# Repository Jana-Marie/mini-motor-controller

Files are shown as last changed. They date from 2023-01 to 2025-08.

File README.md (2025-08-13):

# mini-motor-controller

A motor controller for miniature stepper motors, such as used in CD head drives. The additional ADC input allows for position feedback. This project was intended to be used in a DIY motor fader, however this motorfader has not been designed yet.

It features a cheap STM32F030 as brains with I2C as main IO to the host controller, an onboard regulator allows for an input voltage of up to 10V. The motor driver is a STSPIN220 with up to 1.3Arms.

<table>
  <tbody>
    <tr>
      <td colspan="2">
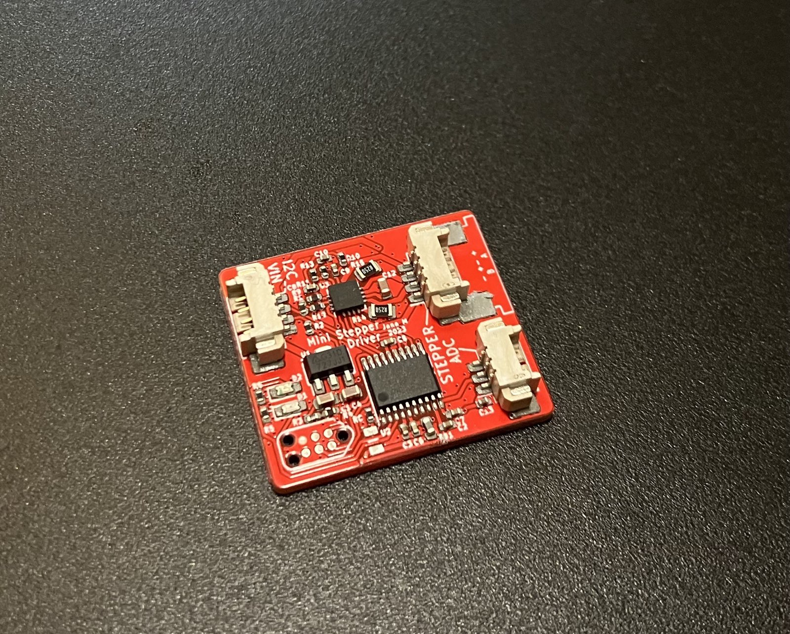
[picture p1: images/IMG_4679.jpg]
        
      </td>
    </tr>
    <tr>
      <td>
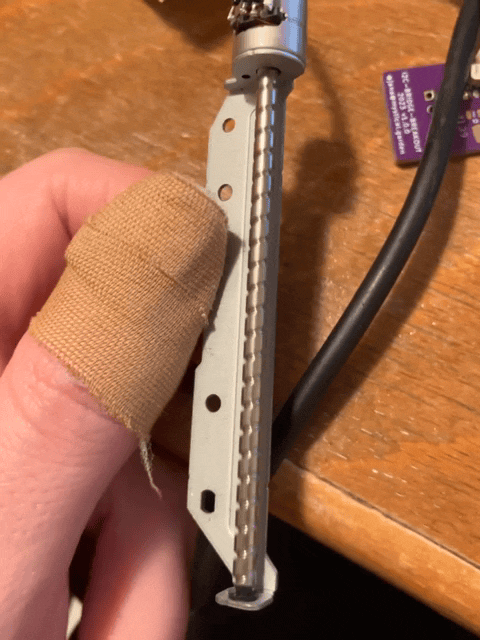
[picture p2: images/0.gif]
        
      </td>
      <td>
        
      </td>
    </tr>
    <tr>
      <td>
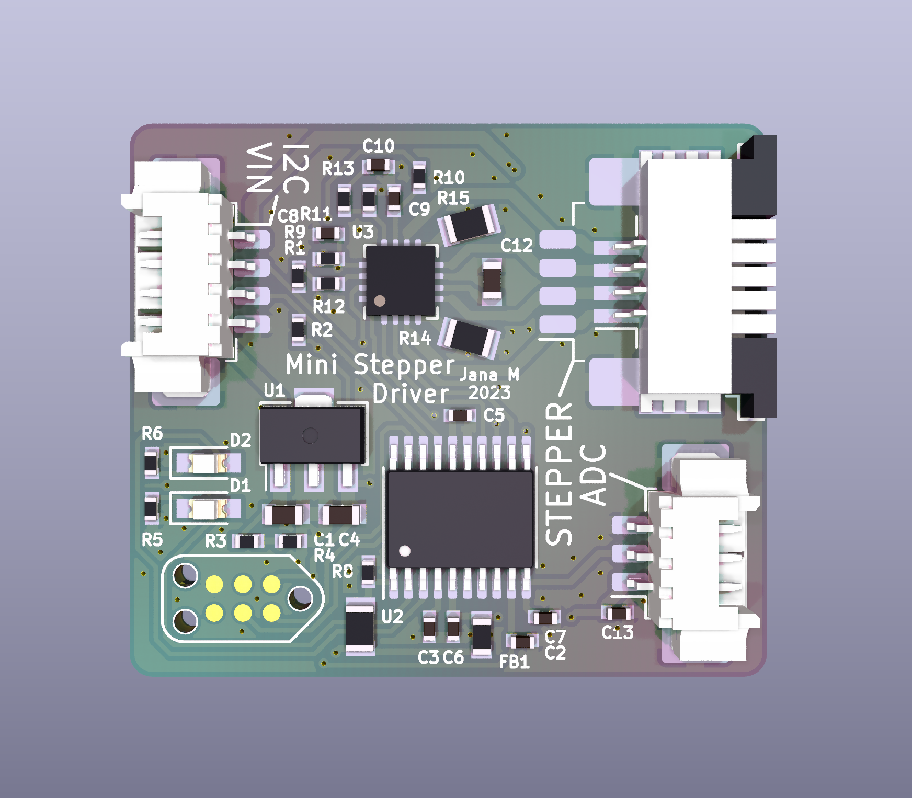
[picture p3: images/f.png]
        
      </td>
      <td>
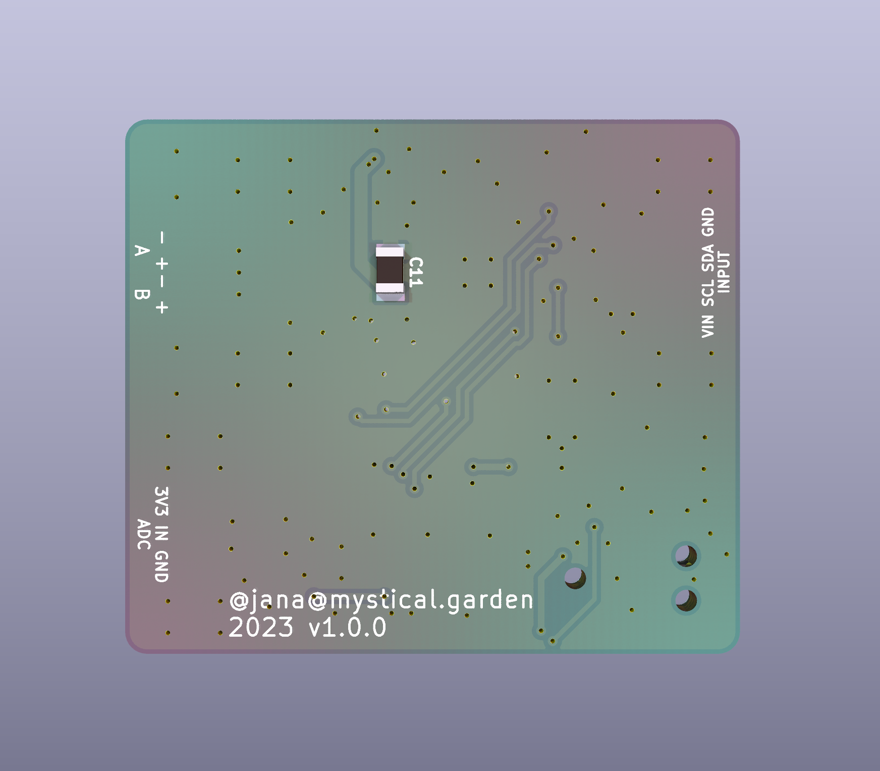
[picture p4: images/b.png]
        
      </td>
    </tr>
  </tbody>
</table>

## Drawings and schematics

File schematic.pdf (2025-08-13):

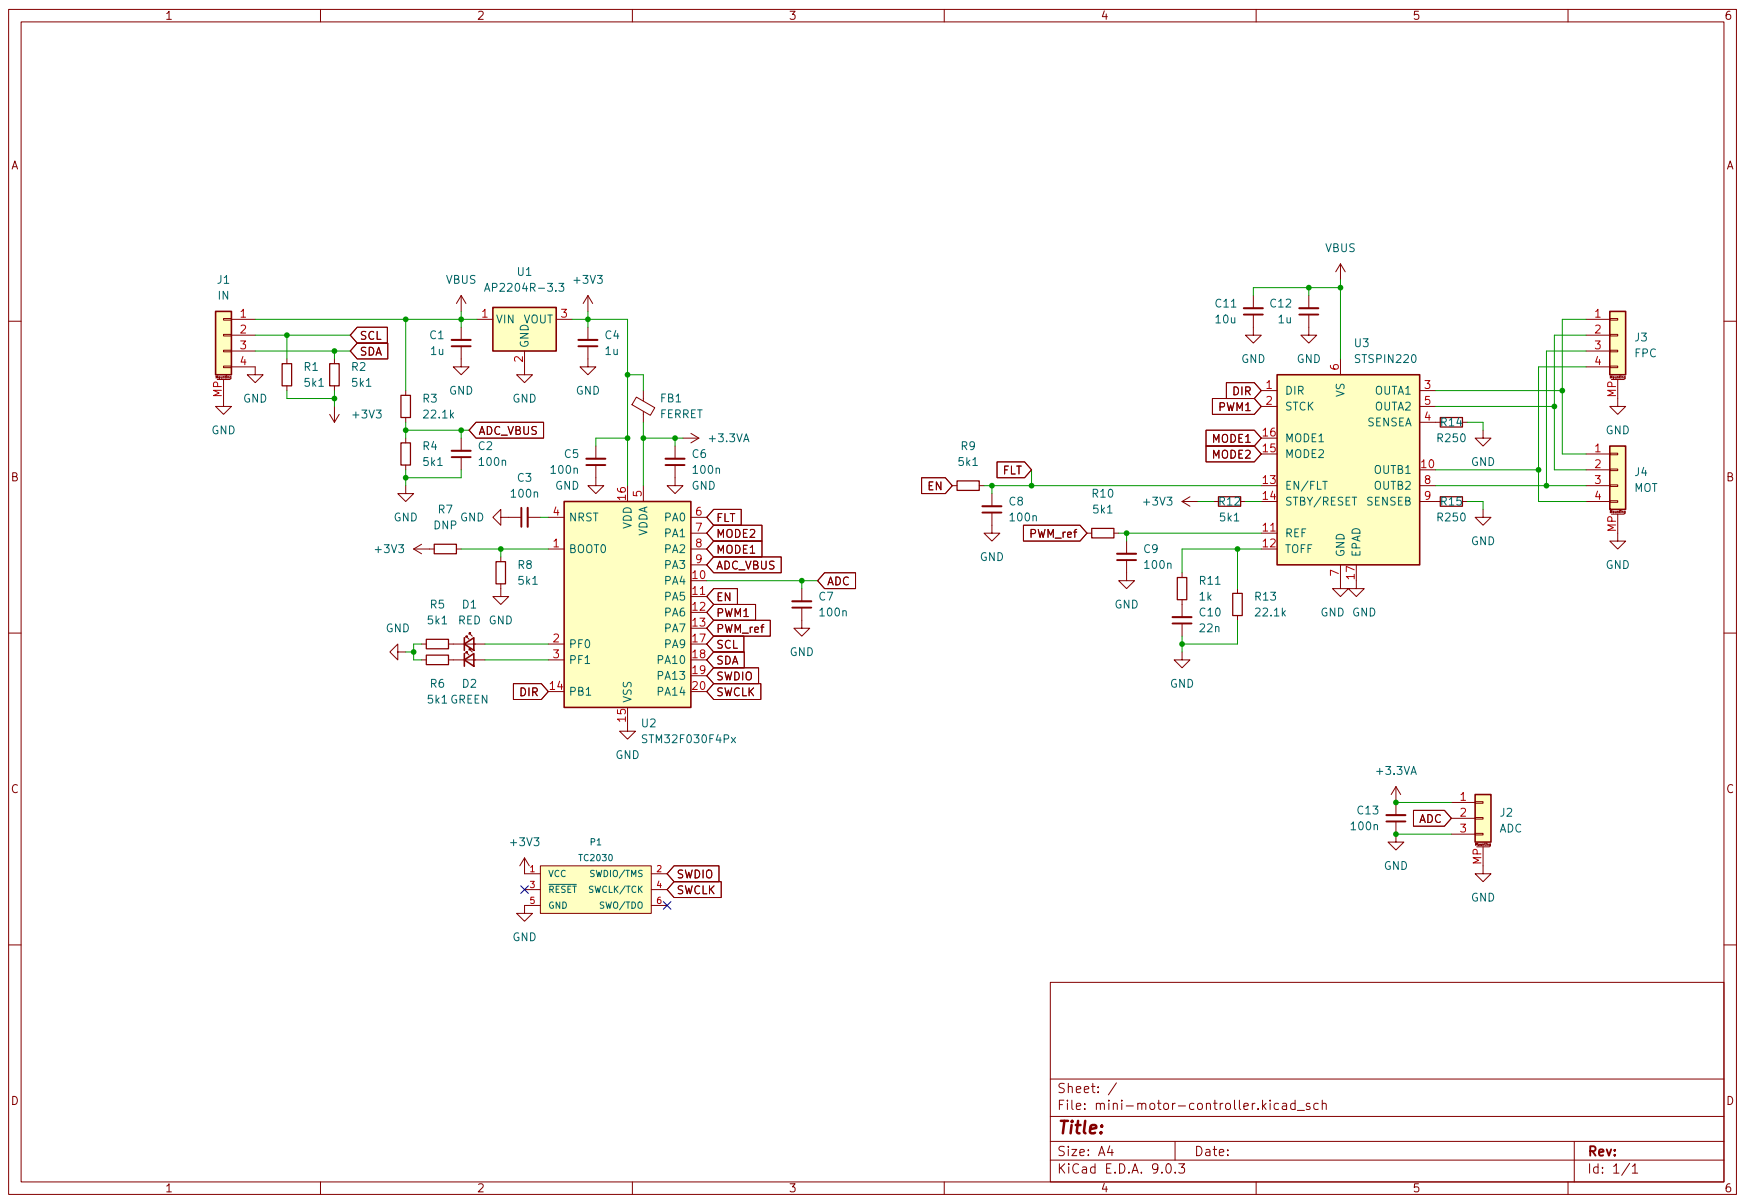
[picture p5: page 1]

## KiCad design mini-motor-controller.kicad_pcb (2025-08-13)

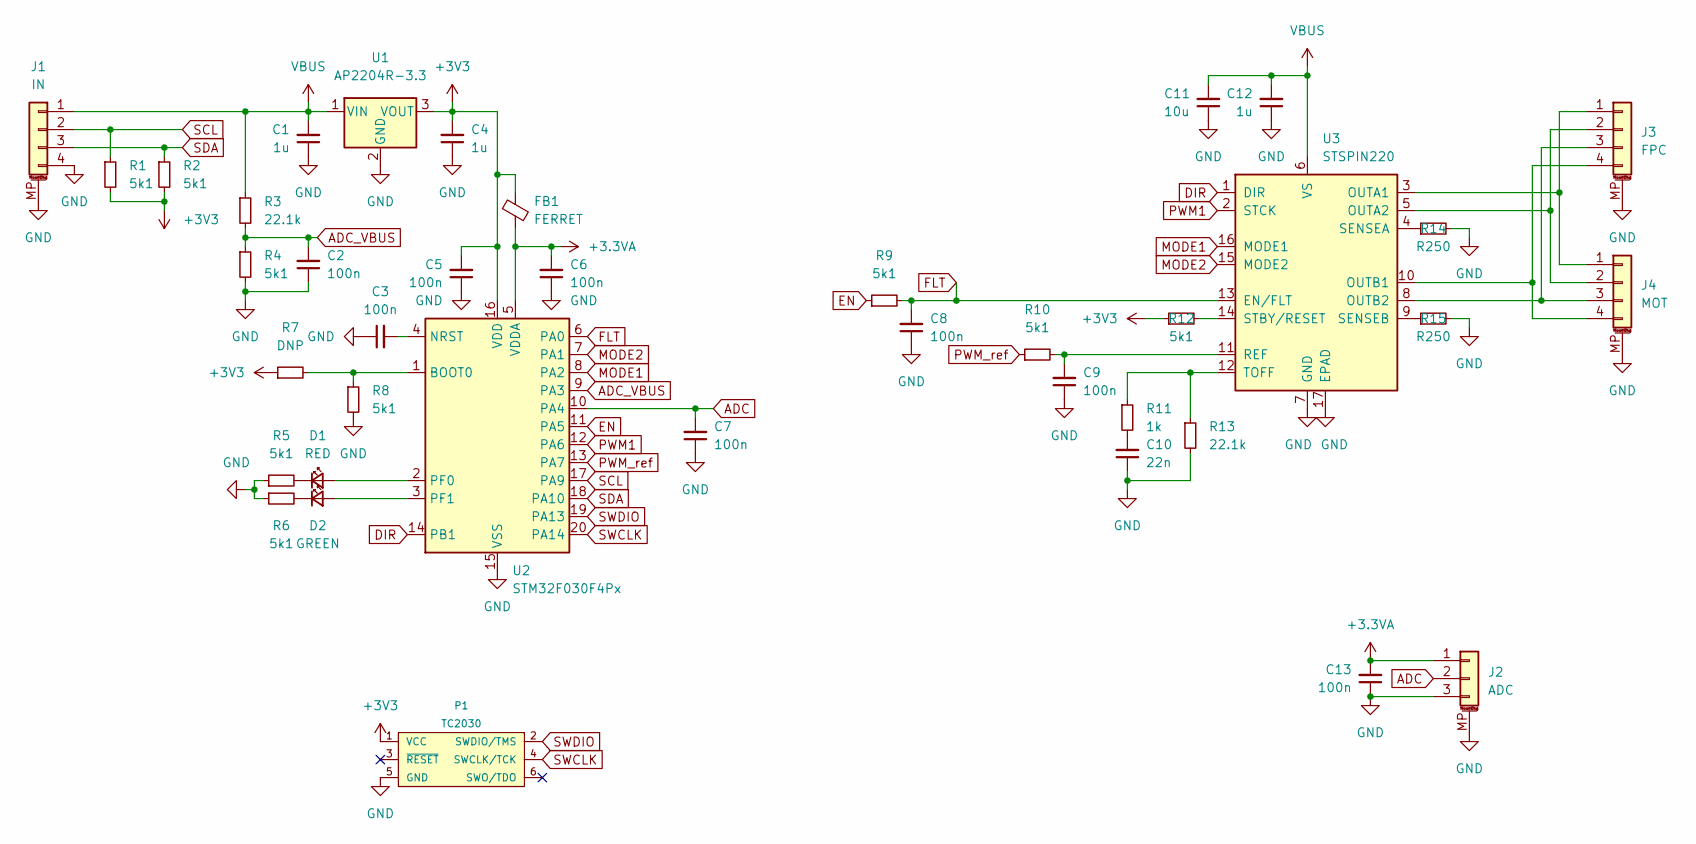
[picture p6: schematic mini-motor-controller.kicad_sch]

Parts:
C1, C4, C12: 1u; C_0603
C2, C3, C5, C6, C7, C8, C9, C13: 100n; C_0402
C10: 22n; C_0402
C11: 10u; C_0805
D1: RED; LED_0603_1608Metric
D2: GREEN; LED_0603_1608Metric
FB1: FERRET; R_0603
J1: IN; Molex_PicoBlade_53261-0471_1x04-1MP_P1.25mm_Horizontal
J2: ADC; Molex_PicoBlade_53261-0371_1x03-1MP_P1.25mm_Horizontal
J3: FPC; TE_84953-4_1x04-1MP_P1.0mm_Horizontal
J4: MOT; Molex_PicoBlade_53261-0471_1x04-1MP_P1.25mm_Horizontal
P1: TC2030
R1, R2, R4, R5, R6, R8, R9, R10, R12: 5k1; R_0402
R3, R13: 22.1k; R_0402
R7: DNP; R_0805
R11: 1k; R_0402
R14, R15: R250; R_0805
U1: AP2204R-3.3; SOT-89-3
U2: STM32F030F4Px; TSSOP-20_4.4x6.5mm_P0.65mm
U3: STSPIN220; VQFN-16-1EP_3x3mm_P0.5mm_EP1.8x1.8mm

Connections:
+3.3VA: C6.2, C13.2, FB1.2, J2.1, U2.5 (VDDA)
+3V3: C4.2, C5.2, FB1.1, P1.1 (VCC), R1.2, R2.2, R7.1, R12.1, U1.3 (VOUT), U2.16 (VDD)
ADC: C7.2, J2.2, U2.10 (PA4)
ADC_VBUS: C2.2, R3.2, R4.1, U2.9 (PA3)
DIR: U2.14 (PB1), U3.1 (DIR)
EN: R9.1, U2.11 (PA5)
FLT: C8.2, R9.2, U2.6 (PA0), U3.13 (EN/FLT)
GND: C1.1, C2.1, C3.1, C4.1, C5.1, C6.1, C7.1, C8.1, C9.1, C10.1, C11.1, C12.1, C13.1, J1.4, J1.MP (MountPin), J2.3, J2.MP (MountPin), J3.MP (MountPin), J4.MP (MountPin), P1.5 (GND), R4.2, R5.1, R6.1, R8.2, R13.2, R14.2, R15.2, U1.2 (GND), U2.15 (VSS), U3.7 (GND), U3.17 (EPAD)
MODE1: U2.8 (PA2), U3.16 (MODE1)
MODE2: U2.7 (PA1), U3.15 (MODE2)
unnamed: C3.2, U2.4 (NRST)
unnamed: C9.2, R10.2, U3.11 (REF)
unnamed: C10.2, R11.2
unnamed: D1.1 (K), R5.2
unnamed: D1.2 (A), U2.2 (PF0)
unnamed: D2.1 (K), R6.2
unnamed: D2.2 (A), U2.3 (PF1)
unnamed: J3.1, J4.1, U3.3 (OUTA1)
unnamed: J3.2, J4.2, U3.5 (OUTA2)
unnamed: R7.2, R8.1, U2.1 (BOOT0)
unnamed: R11.1, R13.1, U3.12 (TOFF)
unnamed: R12.2, U3.14 (STBY/RESET)
unnamed: R14.1, U3.4 (SENSEA)
unnamed: R15.1, U3.9 (SENSEB)
unnamed: J3.3, J4.3, U3.8 (OUTB2)
unnamed: J3.4, J4.4, U3.10 (OUTB1)
PWM1: U2.12 (PA6), U3.2 (STCK)
PWM_ref: R10.1, U2.13 (PA7)
SCL: J1.2, R1.1, U2.17 (PA9)
SDA: J1.3, R2.1, U2.18 (PA10)
SWCLK: P1.4 (SWCLK/TCK), U2.20 (PA14)
SWDIO: P1.2 (SWDIO/TMS), U2.19 (PA13)
VBUS: C1.2, C11.2, C12.2, J1.1, R3.1, U1.1 (VIN), U3.6 (VS)

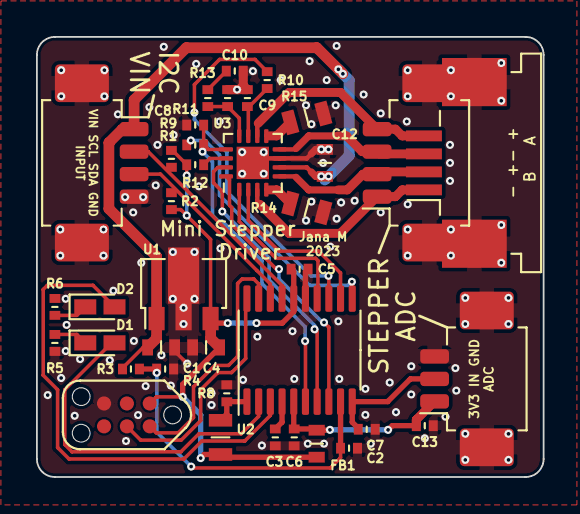
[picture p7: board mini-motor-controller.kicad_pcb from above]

Board: 2 copper layers, 28.2 x 24.5 mm, 39 parts (1 on the bottom side), 33 nets.

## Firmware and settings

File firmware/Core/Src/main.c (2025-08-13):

#include "main.h"

ADC_HandleTypeDef hadc;
DMA_HandleTypeDef hdma_adc;

I2C_HandleTypeDef hi2c1;
DMA_HandleTypeDef hdma_i2c1_rx;
DMA_HandleTypeDef hdma_i2c1_tx;

TIM_HandleTypeDef htim1;
TIM_HandleTypeDef htim3;
TIM_HandleTypeDef htim14;

void SystemClock_Config(void);
static void MX_GPIO_Init(void);
static void MX_DMA_Init(void);
static void MX_ADC_Init(void);
static void MX_I2C1_Init(void);
static void MX_TIM1_Init(void);
static void MX_TIM3_Init(void);
static void MX_TIM14_Init(void);

uint16_t adc[2];
uint16_t vbus;
uint16_t vadc;

uint16_t dir = 0;
uint16_t presc = 46;
uint16_t comp = 1024;

int main(void)
{
  HAL_Init();
  SystemClock_Config();

  MX_GPIO_Init();
  MX_DMA_Init();
  MX_ADC_Init();
  MX_I2C1_Init();
  MX_TIM1_Init();
  MX_TIM3_Init();
  MX_TIM14_Init();

  HAL_GPIO_WritePin(LED_ERR_GPIO_Port, LED_ERR_Pin, 1);
  HAL_GPIO_WritePin(LED_OK_GPIO_Port, LED_OK_Pin, 1);
  HAL_GPIO_WritePin(EN_GPIO_Port, EN_Pin, 0);
  HAL_Delay(1);
  HAL_GPIO_WritePin(MODE2_GPIO_Port, MODE2_Pin, 1); // 1/16 step
  HAL_GPIO_WritePin(MODE1_GPIO_Port, MODE1_Pin, 0); //
  HAL_GPIO_WritePin(GPIOA, GPIO_PIN_6, 0);          //
  HAL_GPIO_WritePin(GPIOB, GPIO_PIN_1, 0);          //
  HAL_Delay(1);
  HAL_GPIO_WritePin(EN_GPIO_Port, EN_Pin, 1);

  HAL_TIM_PWM_Start(&htim14, TIM_CHANNEL_1);
  HAL_GPIO_WritePin(DIR_GPIO_Port, DIR_Pin, dir);

  HAL_ADC_Start_DMA(&hadc, (uint32_t *)adc, 2);
  HAL_TIM_Base_Start(&htim1);
  
  HAL_TIM_PWM_Start(&htim3, TIM_CHANNEL_1);

  HAL_GPIO_WritePin(LED_ERR_GPIO_Port, LED_ERR_Pin, 0);
  while (1)
  {
    HAL_GPIO_WritePin(DIR_GPIO_Port, DIR_Pin, dir);
    __HAL_TIM_SET_PRESCALER(&htim3, presc);
    __HAL_TIM_SET_COMPARE(&htim3, TIM_CHANNEL_1,comp);
    vbus = ((adc[0]*3300/4095)*272/51 + vbus * 3) / 4;
    vadc = ((adc[1]*3300/4095) + vadc * 3) / 4;
    HAL_Delay(50);
  }
}

void SystemClock_Config(void)
{
  RCC_OscInitTypeDef RCC_OscInitStruct = {0};
  RCC_ClkInitTypeDef RCC_ClkInitStruct = {0};
  RCC_PeriphCLKInitTypeDef PeriphClkInit = {0};

  RCC_OscInitStruct.OscillatorType = RCC_OSCILLATORTYPE_HSI|RCC_OSCILLATORTYPE_HSI14;
  RCC_OscInitStruct.HSIState = RCC_HSI_ON;
  RCC_OscInitStruct.HSI14State = RCC_HSI14_ON;
  RCC_OscInitStruct.HSICalibrationValue = RCC_HSICALIBRATION_DEFAULT;
  RCC_OscInitStruct.HSI14CalibrationValue = 16;
  RCC_OscInitStruct.PLL.PLLState = RCC_PLL_ON;
  RCC_OscInitStruct.PLL.PLLSource = RCC_PLLSOURCE_HSI;
  RCC_OscInitStruct.PLL.PLLMUL = RCC_PLL_MUL12;
  RCC_OscInitStruct.PLL.PREDIV = RCC_PREDIV_DIV1;
  HAL_RCC_OscConfig(&RCC_OscInitStruct);


  RCC_ClkInitStruct.ClockType = RCC_CLOCKTYPE_HCLK|RCC_CLOCKTYPE_SYSCLK
                              |RCC_CLOCKTYPE_PCLK1;
  RCC_ClkInitStruct.SYSCLKSource = RCC_SYSCLKSOURCE_PLLCLK;
  RCC_ClkInitStruct.AHBCLKDivider = RCC_SYSCLK_DIV1;
  RCC_ClkInitStruct.APB1CLKDivider = RCC_HCLK_DIV1;
  HAL_RCC_ClockConfig(&RCC_ClkInitStruct, FLASH_LATENCY_1);

  PeriphClkInit.PeriphClockSelection = RCC_PERIPHCLK_I2C1;
  PeriphClkInit.I2c1ClockSelection = RCC_I2C1CLKSOURCE_HSI;
  HAL_RCCEx_PeriphCLKConfig(&PeriphClkInit);
}

static void MX_ADC_Init(void)
{
  ADC_ChannelConfTypeDef sConfig = {0};

  hadc.Instance = ADC1;
  hadc.Init.ClockPrescaler = ADC_CLOCK_ASYNC_DIV1;
  hadc.Init.Resolution = ADC_RESOLUTION_12B;
  hadc.Init.DataAlign = ADC_DATAALIGN_RIGHT;
  hadc.Init.ScanConvMode = ADC_SCAN_DIRECTION_FORWARD;
  hadc.Init.EOCSelection = ADC_EOC_SEQ_CONV;
  hadc.Init.LowPowerAutoWait = DISABLE;
  hadc.Init.LowPowerAutoPowerOff = DISABLE;
  hadc.Init.ContinuousConvMode = DISABLE;
  hadc.Init.DiscontinuousConvMode = DISABLE;
  hadc.Init.ExternalTrigConv = ADC_EXTERNALTRIGCONV_T1_TRGO;
  hadc.Init.ExternalTrigConvEdge = ADC_EXTERNALTRIGCONVEDGE_RISING;
  hadc.Init.DMAContinuousRequests = ENABLE;
  hadc.Init.Overrun = ADC_OVR_DATA_OVERWRITTEN;
  HAL_ADC_Init(&hadc);

  sConfig.Channel = ADC_CHANNEL_3;
  sConfig.Rank = ADC_RANK_CHANNEL_NUMBER;
  sConfig.SamplingTime = ADC_SAMPLETIME_7CYCLES_5;
  HAL_ADC_ConfigChannel(&hadc, &sConfig);

  sConfig.Channel = ADC_CHANNEL_4;
  HAL_ADC_ConfigChannel(&hadc, &sConfig);
}

static void MX_I2C1_Init(void)
{
  hi2c1.Instance = I2C1;
  hi2c1.Init.Timing = 0x0000020B;
  hi2c1.Init.OwnAddress1 = 84;
  hi2c1.Init.AddressingMode = I2C_ADDRESSINGMODE_7BIT;
  hi2c1.Init.DualAddressMode = I2C_DUALADDRESS_DISABLE;
  hi2c1.Init.OwnAddress2 = 0;
  hi2c1.Init.OwnAddress2Masks = I2C_OA2_NOMASK;
  hi2c1.Init.GeneralCallMode = I2C_GENERALCALL_DISABLE;
  hi2c1.Init.NoStretchMode = I2C_NOSTRETCH_ENABLE;
  HAL_I2C_Init(&hi2c1);

  HAL_I2CEx_ConfigAnalogFilter(&hi2c1, I2C_ANALOGFILTER_ENABLE);
  HAL_I2CEx_ConfigDigitalFilter(&hi2c1, 0);
}

static void MX_TIM1_Init(void)
{
  TIM_ClockConfigTypeDef sClockSourceConfig = {0};
  TIM_MasterConfigTypeDef sMasterConfig = {0};

  htim1.Instance = TIM1;
  htim1.Init.Prescaler = 10;
  htim1.Init.CounterMode = TIM_COUNTERMODE_UP;
  htim1.Init.Period = 48000;
  htim1.Init.ClockDivision = TIM_CLOCKDIVISION_DIV1;
  htim1.Init.RepetitionCounter = 0;
  htim1.Init.AutoReloadPreload = TIM_AUTORELOAD_PRELOAD_ENABLE;
  HAL_TIM_Base_Init(&htim1);

  sClockSourceConfig.ClockSource = TIM_CLOCKSOURCE_INTERNAL;
  HAL_TIM_ConfigClockSource(&htim1, &sClockSourceConfig);

  sMasterConfig.MasterOutputTrigger = TIM_TRGO_UPDATE;
  sMasterConfig.MasterSlaveMode = TIM_MASTERSLAVEMODE_DISABLE;
  HAL_TIMEx_MasterConfigSynchronization(&htim1, &sMasterConfig);
}

static void MX_TIM3_Init(void)
{
  TIM_MasterConfigTypeDef sMasterConfig = {0};
  TIM_OC_InitTypeDef sConfigOC = {0};

  htim3.Instance = TIM3;
  htim3.Init.Prescaler = 46;
  htim3.Init.CounterMode = TIM_COUNTERMODE_UP;
  htim3.Init.Period = 1024;
  htim3.Init.ClockDivision = TIM_CLOCKDIVISION_DIV1;
  htim3.Init.AutoReloadPreload = TIM_AUTORELOAD_PRELOAD_ENABLE;
  HAL_TIM_PWM_Init(&htim3);

  sMasterConfig.MasterOutputTrigger = TIM_TRGO_RESET;
  sMasterConfig.MasterSlaveMode = TIM_MASTERSLAVEMODE_DISABLE;
  HAL_TIMEx_MasterConfigSynchronization(&htim3, &sMasterConfig);

  sConfigOC.OCMode = TIM_OCMODE_PWM1;
  sConfigOC.Pulse = 512;
  sConfigOC.OCPolarity = TIM_OCPOLARITY_HIGH;
  sConfigOC.OCFastMode = TIM_OCFAST_DISABLE;
  HAL_TIM_PWM_ConfigChannel(&htim3, &sConfigOC, TIM_CHANNEL_1);
  HAL_TIM_MspPostInit(&htim3);
}

static void MX_TIM14_Init(void)
{
  TIM_OC_InitTypeDef sConfigOC = {0};

  htim14.Instance = TIM14;
  htim14.Init.Prescaler = 46;
  htim14.Init.CounterMode = TIM_COUNTERMODE_UP;
  htim14.Init.Period = 1024;
  htim14.Init.ClockDivision = TIM_CLOCKDIVISION_DIV1;
  htim14.Init.AutoReloadPreload = TIM_AUTORELOAD_PRELOAD_ENABLE;
  HAL_TIM_Base_Init(&htim14);
  HAL_TIM_PWM_Init(&htim14);

  sConfigOC.OCMode = TIM_OCMODE_PWM1;
  sConfigOC.Pulse = 12;
  sConfigOC.OCPolarity = TIM_OCPOLARITY_HIGH;
  sConfigOC.OCFastMode = TIM_OCFAST_DISABLE;
  HAL_TIM_PWM_ConfigChannel(&htim14, &sConfigOC, TIM_CHANNEL_1);
  HAL_TIM_MspPostInit(&htim14);
}

static void MX_DMA_Init(void)
{
  __HAL_RCC_DMA1_CLK_ENABLE();

  HAL_NVIC_SetPriority(DMA1_Channel1_IRQn, 0, 0);
  HAL_NVIC_EnableIRQ(DMA1_Channel1_IRQn);
  HAL_NVIC_SetPriority(DMA1_Channel2_3_IRQn, 0, 0);
  HAL_NVIC_EnableIRQ(DMA1_Channel2_3_IRQn);
}

static void MX_GPIO_Init(void)
{
  GPIO_InitTypeDef GPIO_InitStruct = {0};
  __HAL_RCC_GPIOF_CLK_ENABLE();
  __HAL_RCC_GPIOA_CLK_ENABLE();
  __HAL_RCC_GPIOB_CLK_ENABLE();

  HAL_GPIO_WritePin(GPIOF, GPIO_PIN_0|GPIO_PIN_1, GPIO_PIN_RESET);
  HAL_GPIO_WritePin(GPIOA, GPIO_PIN_1|GPIO_PIN_2|GPIO_PIN_5, GPIO_PIN_RESET);
  HAL_GPIO_WritePin(GPIOB, GPIO_PIN_1, GPIO_PIN_RESET);

  GPIO_InitStruct.Pin = GPIO_PIN_0|GPIO_PIN_1;
  GPIO_InitStruct.Mode = GPIO_MODE_OUTPUT_PP;
  GPIO_InitStruct.Pull = GPIO_NOPULL;
  GPIO_InitStruct.Speed = GPIO_SPEED_FREQ_LOW;
  HAL_GPIO_Init(GPIOF, &GPIO_InitStruct);

  GPIO_InitStruct.Pin = GPIO_PIN_0;
  GPIO_InitStruct.Mode = GPIO_MODE_IT_RISING;
  GPIO_InitStruct.Pull = GPIO_NOPULL;
  HAL_GPIO_Init(GPIOA, &GPIO_InitStruct);

  GPIO_InitStruct.Pin = GPIO_PIN_1|GPIO_PIN_2|GPIO_PIN_5;
  GPIO_InitStruct.Mode = GPIO_MODE_OUTPUT_PP;
  GPIO_InitStruct.Pull = GPIO_NOPULL;
  GPIO_InitStruct.Speed = GPIO_SPEED_FREQ_LOW;
  HAL_GPIO_Init(GPIOA, &GPIO_InitStruct);

  GPIO_InitStruct.Pin = GPIO_PIN_1;
  GPIO_InitStruct.Mode = GPIO_MODE_OUTPUT_PP;
  GPIO_InitStruct.Pull = GPIO_NOPULL;
  GPIO_InitStruct.Speed = GPIO_SPEED_FREQ_LOW;
  HAL_GPIO_Init(GPIOB, &GPIO_InitStruct);

}

void Error_Handler(void)
{
  __disable_irq();
  while (1)
  {
  }
}

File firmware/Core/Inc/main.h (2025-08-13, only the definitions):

#define LED_ERR_Pin GPIO_PIN_0
#define LED_ERR_GPIO_Port GPIOF
#define LED_OK_Pin GPIO_PIN_1
#define LED_OK_GPIO_Port GPIOF
#define FAULT_Pin GPIO_PIN_0
#define FAULT_GPIO_Port GPIOA
#define MODE2_Pin GPIO_PIN_1
#define MODE2_GPIO_Port GPIOA
#define MODE1_Pin GPIO_PIN_2
#define MODE1_GPIO_Port GPIOA
#define EN_Pin GPIO_PIN_5
#define EN_GPIO_Port GPIOA
#define STEP_Pin GPIO_PIN_6
#define STEP_GPIO_Port GPIOA
#define PWM_ref_Pin GPIO_PIN_7
#define PWM_ref_GPIO_Port GPIOA
#define DIR_Pin GPIO_PIN_1
#define DIR_GPIO_Port GPIOB

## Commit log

2023-01-02 added source files
    [mini-motor-controller.kicad_pcb, mini-motor-controller.kicad_sch]
2025-08-13 bumped files
    [mini-motor-controller.kicad_pcb, mini-motor-controller.kicad_sch]
2025-08-13 added schematic
2025-08-13 updated schematic

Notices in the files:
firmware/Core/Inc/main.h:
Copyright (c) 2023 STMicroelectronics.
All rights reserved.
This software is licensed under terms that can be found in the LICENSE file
